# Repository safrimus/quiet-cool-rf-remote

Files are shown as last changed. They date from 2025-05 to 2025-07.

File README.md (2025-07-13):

# Quiet Cool RF Remote with ESPHOME
Operate your remote controlled QuietCool Fan from ESPHome or Arduino.

This project implements an RF remote control system for Quiet Cool fans using an ESP32 microcontroller and CC1101 RF module.
The system can control various fan speeds and modes through RF signals.

## WARNING WARNING WARNING
**This should have been obvious to me before.  Alas, it wasn't.  Each RF remote has a unique ID built-in, and this code literally
only works with my remote for that reason.  Currently, getting this working will take some effort decoding your individual remote. 
Lame, I know.  Whatcha gonna do?
**

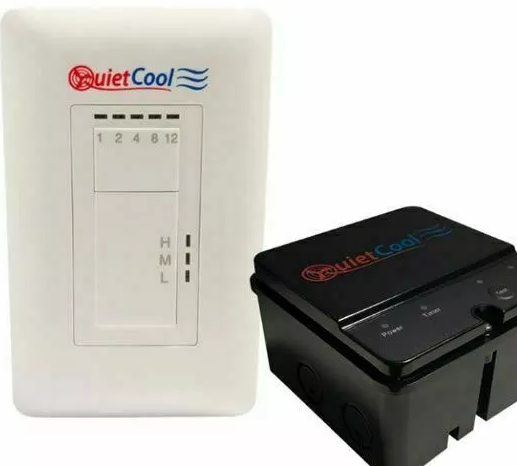
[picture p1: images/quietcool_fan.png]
QuietCool Remote


# TL;DR -- get it running on ESPHome
Get a generateic CC1101 board.  Like this [CC1101 Board](https://www.amazon.com/dp/B0D3W9GVRQ?ref=ppx_yo2ov_dt_b_fed_asin_title)

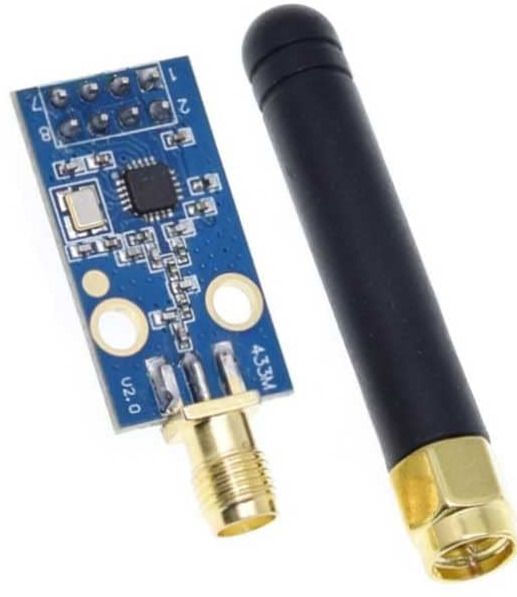
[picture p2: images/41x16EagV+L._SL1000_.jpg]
CC1101


Make these connections from your ESP32 to your CC1101 chip/board.

NOTE: the pinouts on these boards seem to be not reliable.  I had to trace them manually to figure out which header pin went to which CC1101 pin.  

| Module Pin | CC1101 Pin Name | CC1101 Pin #| ESP32 Pin |
|---|---|---|---|
| 1 | GND | 16,19,PAD | GND |
| 2 | VCC | - | 3.3V |
| 3 | GDO0 | 6 | GPIO13 |
| 4 | CSn | 7 | GPIO15 |
| 5 | SCK | 1 | GPIO18 |
| 6 | MOSI | 20 | GPIO23 |
| 7 | MISO | 2 | GPIO19 |
| 8 | GDO2 | 3 | GPIO12 |

## TL;DR -- get it running on ESPHome from ESPHome Builder on HomeAssistant

* Go to ESPHome Builder
* Click "+ NEW DEVICE" at the bottom of the screen
* Click `CONTINUE`
* name your fan
* click the ESP32 type you have.
* click `SKIP`
* on your new entry, click `EDIT`
* add the following to the bottom of the file:
```yaml
spi:
  clk_pin: 18
  mosi_pin: 23
  miso_pin: 19

external_components:
  - source:
      type: git
      url: https://github.com/ccrome/quiet-cool-rf-remote.git
      ref: main
    components: [ quiet_cool ]

fan:
  - platform: quiet_cool
    name: QuietCool fan
    cs_pin: 15
    gdo0_pin: 13
    gdo2_pin: 12
    remote_id: [0x2D, 0xD4, 0x06, 0xCB, 0x00, 0xF7, 0xF2]
# optional variables
#    center_freq_mhz: 433.897
#    deviation_khz: 10
```
* click `INSTALL` and install it in the normal ESPHome ways...

## TL;DR -- get it running on ESPHome, building locally

Create a `secrets.yaml` file
```yaml
wifi_ssid: <ssid>
wifi_password: <wifi password>
api_enctryption_key: <api key>
ota_password: <ota password>
```

compile, upload, and run
```
esphome compile quietcool-fan-example.yaml && \
esphome upload --device /dev/ttyUSB0 quietcool-fan-example.yaml  && \
esphome logs --device /dev/ttyUSB0 quietcool-fan-example.yaml
```

If everything is working, you should see
```
[16:48:24][D][quietcool:168]: gdo0_pin = 13, gdo2_pin = 12
[16:48:24][I][quietcool:174]: Starting CC1101 setup
[16:48:24][D][quietcool:041]: sck:18, miso:19, mosi:23, csn:15
[16:48:24][I][quietcool:047]: CC1101 VERSION READ: 0x00
[16:48:24][I][quietcool:047]: CC1101 VERSION READ: 0x14
[16:48:24][I][quietcool:049]: CC1101 detected!
[16:48:24][I][quietcool:179]: CC1101 ready
[16:48:24][D][empty_fan.fan:022]: QuietCool initialized
```

# Configuration

## Required Configuration

The `remote_id` field is **required** and must match your specific QuietCool remote. This is a 7-byte identifier that uniquely identifies your remote control.

> **Note:** QuietCool fans can pair with multiple remotes. This means you may not need to decode your existing remote's ID. Instead, you can simply pair this new ESPHome-based remote (with its own `remote_id`) to your fan, and both your original remote and the Home Assistant remote should work together.  This has yet to be tested.

### Finding Your Remote ID

NOTE:  you may not need to decode your existing remote's ID.  Instead, you can simply pair this new ESPHome-based remote (with its own `remote_id`) to your fan, and both your original remote and the Home Assistant remote should work together.  This has yet to be tested.

To find your remote ID, you can:
1. Use an RTL-SDR to capture signals from your physical remote
2. Analyze the captured signals to extract the remote ID
3. Or use the default value as a starting point: `[0x2D, 0xD4, 0x06, 0xCB, 0x00, 0xF7, 0xF2]`

### Example Configuration

```yaml
fan:
  - platform: quiet_cool
    name: QuietCool fan
    cs_pin: 15
    gdo0_pin: 13
    gdo2_pin: 12
    remote_id: [0x2D, 0xD4, 0x06, 0xCB, 0x00, 0xF7, 0xF2]
    # Optional:
    # center_freq_mhz: 433.897
    # deviation_khz: 10
```

---

### QuietCool YAML Configuration Options

| Option | Required | Type | Default | Description |
|---|---|---|---|---|
| `name` | Yes | string | | The name of the fan in Home Assistant. |
| `platform` | Yes | string | | Must be `quiet_cool`. |
| `cs_pin` | Yes | int | | SPI chip select pin for CC1101. |
| `gdo0_pin` | Yes | int | | GDO0 pin from CC1101 (used for TX status). |
| `gdo2_pin` | Yes | int | | GDO2 pin from CC1101 (can be -1 if unused). |
| `remote_id` | Yes | list[hex] | | 7-byte unique ID for your remote (see above). |
| `center_freq_mhz` | No | float | 433.897 | Center frequency in MHz for RF transmission. |
| `deviation_khz` | No | float | 10 | Frequency deviation (spread) in kHz for FSK modulation. |

**Note:** You must also define the SPI bus pins in your YAML:

```yaml
spi:
  clk_pin: 18
  mosi_pin: 23
  miso_pin: 19
```

## Recent Improvements

### Transmission System Overhaul
- **Consolidated bit conversion logic**: Unified logging and transmission to ensure consistency
- **Improved reliability**: Fixed potential timing and synchronization issues
- **Better debugging**: Enhanced logging with bit-level visibility
- **Configurable remote ID**: Support for custom remote identifiers via YAML configuration

### Technical Changes
- Replaced string-based command system with byte arrays for better performance
- Consolidated `logBits` and `sendBitsFromBytes` functions to use shared logic
- Added configurable `remote_id` parameter throughout the stack
- Improved error handling and validation

# Run it on arduino
The arduino code doesn't do much by itself.  But it gets you going:

```
cd arduino
platformio run --target upload
```

## Hardware Requirements

- ESP32 DOIT DevKit V1
- CC1101 RF Module
- Wiring connections as follows:
  ```
  CC1101 Pin -> ESP32 Pin
  GND       -> GND
  VCC       -> 3.3V
  GDO0      -> GPIO13
  CSn       -> GPIO15
  SCK       -> GPIO18
  MOSI      -> GPIO23
  MISO      -> GPIO19
  GDO2      -> GPIO12
  ```

## Case
Here's a case for the parts that I used.

The source is here [in OnShape](https://cad.onshape.com/documents/23ba2be84b2f4dcf9bfd73fc/v/3fa4bea9b4bb4353b99b35e1/e/0985333c7a3d43ad0383c966)

### Step File

* The whole design: [QuietCoolCase.step](3d/step/QuietCoolCase.step)
* Or just the Top: [QuietCoolCaseTop.step](3d/step/QuietCoolCaseTop.step)
* and just the Bottom: [QuietCoolCaseBottom.step](3d/step/QuietCoolCaseBottom.step)

## Software Requirements

- PlatformIO

## Features

- Controls Quiet Cool fan system via RF signals
- Supports multiple fan speeds and timer durations
  - Speed
    - L
    - M
    - H
  - Duration
    - 1
    - 2
    - 4
    - 8
    - 12
    - off
    - on
- **Configurable remote ID** for compatibility with different remotes

# Reverse Engineering
I used an RTL-SDR.COM SDR like this:
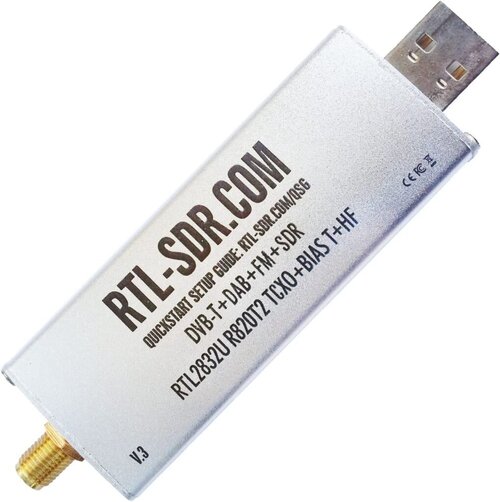
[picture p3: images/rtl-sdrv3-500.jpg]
RTL-SDR v3


And for software, I used Universal Radio Haacker.  Here's a recording of all the signals as they progress from H 1 2 4 8 12 ON OFF -> to medium -> low.  It was recorded with these settings

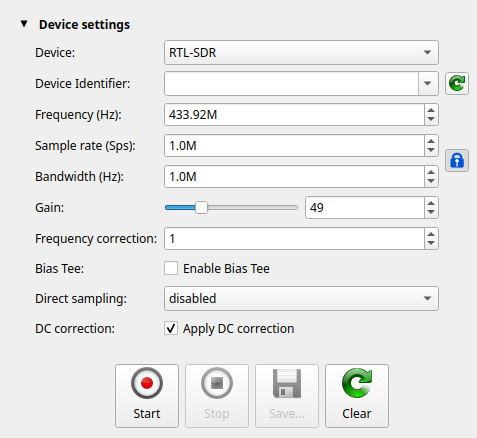
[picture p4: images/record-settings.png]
Settings


[Download the raw recording](recordings/RTL-SDR-20250510_080358-433_92MHz-1MSps-1MHz.complex16s.gz)

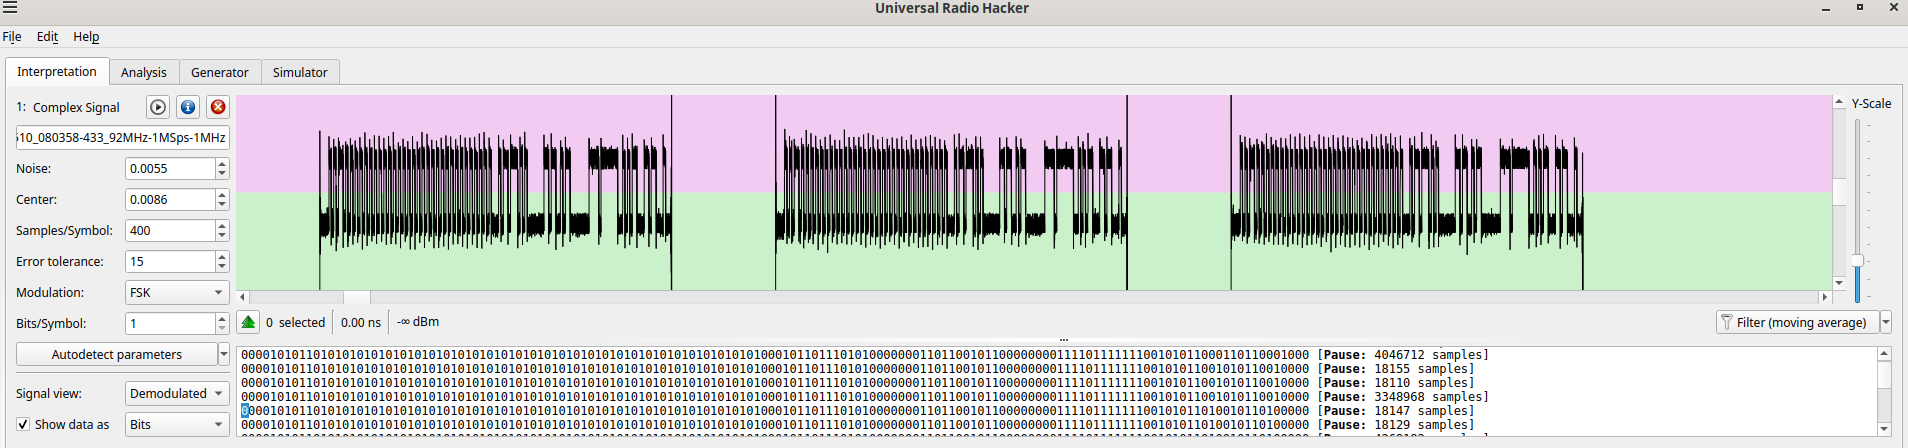
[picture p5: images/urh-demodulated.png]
Here's the signal demodulated


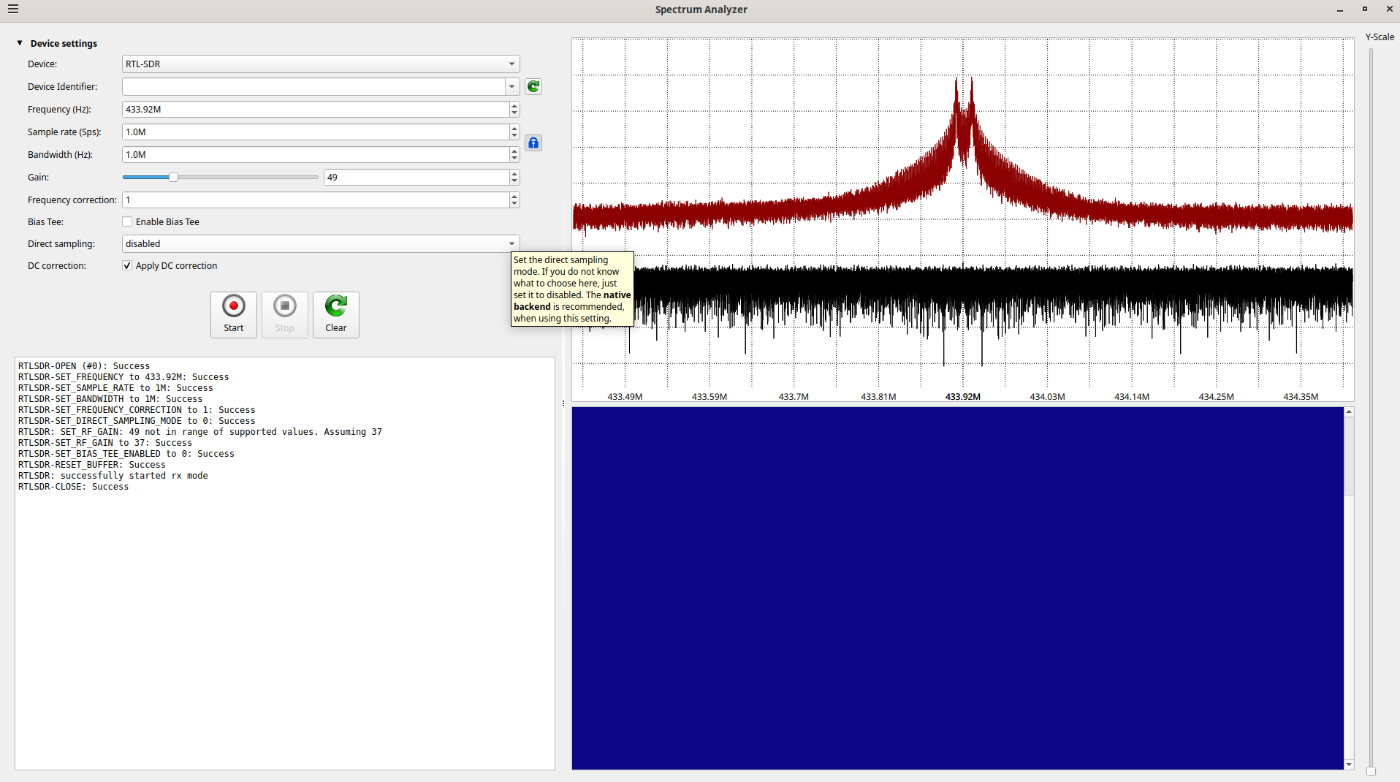
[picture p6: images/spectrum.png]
Spectrum Analysis


## Modulation
This remote uses FSK modulation at 433.92MHz.  The CC1101 RF module ended up transmitting high, so I reduced the frequency in the code to 433.897 to make it work.  If things don't work, check the actual frequency.

## Configuration

The system operates at 433.897 MHz and uses FSK modulation. The CC1101 module is configured for:
- Direct mode transmission
- No packet handling
- Raw data mode
- No CRC or preamble

## Building and Uploading

```pio run --target upload```

# TODO
* Implement the timers in the esphome UI

## License
MIT License

## Contributing

Contributions are welcome! Please feel free to submit a Pull Request.

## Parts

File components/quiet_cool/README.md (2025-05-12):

```yaml
# example configuration:

fan:
  - platform: quiet_cool
    name: QuietCool fan
    output: gpio_d1

output:
  - platform: gpio
    pin: D1
    id: gpio_d1
```

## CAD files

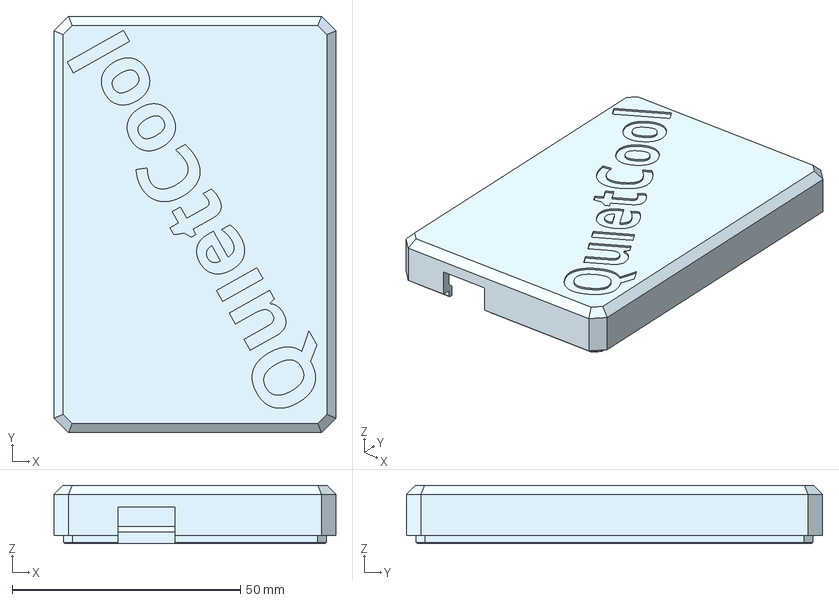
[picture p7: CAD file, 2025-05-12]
3d/step/QuietCoolCaseBottom.step
61.8 x 91.2 x 12.8 mm

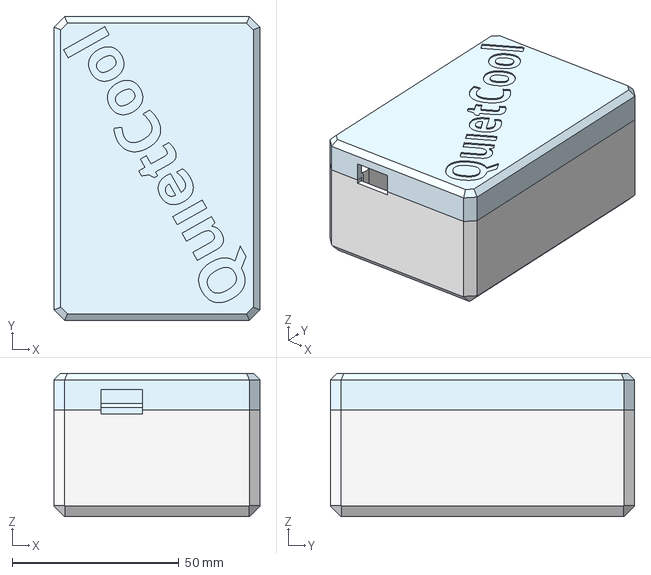
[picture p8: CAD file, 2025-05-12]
3d/step/QuietCoolCase.step
61.8 x 91.2 x 43.0 mm

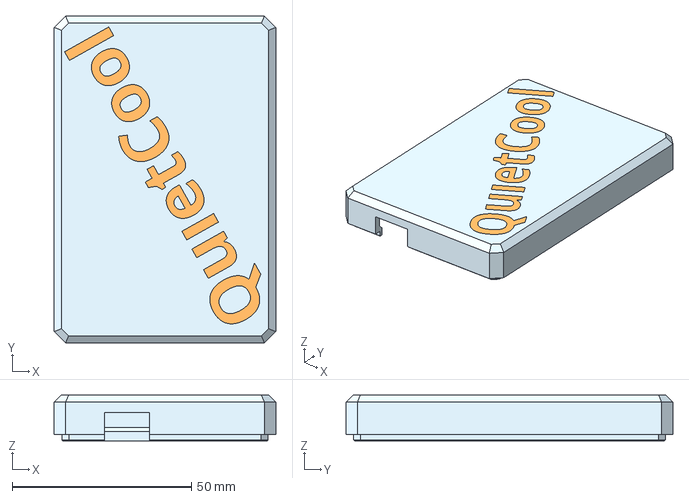
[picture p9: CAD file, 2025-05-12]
3d/step/QuietCoolCaseTop.step
61.8 x 91.2 x 12.8 mm

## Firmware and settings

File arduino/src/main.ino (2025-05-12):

#include <Arduino.h>
#include "quietcool.h"

/*
  hdr   cc1101
  1      19  GND
  2      18  VCC
  3      6   GDO0
  4      7   CSn
  5      1   SCK
  6      20  MOSI
  7      2   MISO
  8      3   GDO2
*/

// --- Pin configuration ---
#define CSN_PIN   15
#define GDO0_PIN  13
#define GDO2_PIN  12
#define SCK_PIN   18
#define MISO_PIN  19
#define MOSI_PIN  23
// #define FREQ_MHZ  433.92
#define FREQ_MHZ  433.897

// Create QuietCool instance with pin configuration
QuietCool qc(CSN_PIN, GDO0_PIN, GDO2_PIN, SCK_PIN, MISO_PIN, MOSI_PIN);

// --- Arduino setup ---
void setup() {
    Serial.begin(115200);
    delay(1000);
    qc.begin();
}

void loop() {
    // Example: Send a command to turn on high speed for 1 hour
    qc.send(QUIETCOOL_SPEED_HIGH, QUIETCOOL_DURATION_1H);
    delay(20000);  // Wait 5 seconds

    // Example: Turn off the fan
    qc.send(QUIETCOOL_SPEED_OFF, QUIETCOOL_DURATION_1H);
    delay(20000);  // Wait 5 seconds
}

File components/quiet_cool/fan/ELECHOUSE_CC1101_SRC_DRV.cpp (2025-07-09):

/*
  ELECHOUSE_CC1101.cpp - CC1101 module library
  Copyright (c) 2010 Michael.
    Author: Michael, <www.elechouse.com>
    Version: November 12, 2010

  This library is designed to use CC1101/CC1100 module on Arduino platform.
  CC1101/CC1100 module is an useful wireless module.Using the functions of the 
  library, you can easily send and receive data by the CC1101/CC1100 module. 
  Just have fun!
  For the details, please refer to the datasheet of CC1100/CC1101.
----------------------------------------------------------------------------------------------------------------
cc1101 Driver for RC Switch. Mod by Little Satan. With permission to modify and publish Wilson Shen (ELECHOUSE).
----------------------------------------------------------------------------------------------------------------
*/
#include <SPI.h>
#include "ELECHOUSE_CC1101_SRC_DRV.h"
#include <Arduino.h>

/****************************************************************/
#define   WRITE_BURST       0x40            //write burst
#define   READ_SINGLE       0x80            //read single
#define   READ_BURST        0xC0            //read burst
#define   BYTES_IN_RXFIFO   0x7F            //byte number in RXfifo
#define   max_modul 6

byte modulation = 2;
byte frend0;
byte chan = 0;
int pa = 12;
byte last_pa;
byte SCK_PIN;
byte MISO_PIN;
byte MOSI_PIN;
byte SS_PIN;
byte GDO0;
byte GDO2;
byte SCK_PIN_M[max_modul];
byte MISO_PIN_M[max_modul];
byte MOSI_PIN_M[max_modul];
byte SS_PIN_M[max_modul];
byte GDO0_M[max_modul];
byte GDO2_M[max_modul];
byte gdo_set=0;
bool spi = 0;
bool ccmode = 0;
float MHz = 433.92;
byte m4RxBw = 0;
byte m4DaRa;
byte m2DCOFF;
byte m2MODFM;
byte m2MANCH;
byte m2SYNCM;
byte m1FEC;
byte m1PRE;
byte m1CHSP;
byte pc1PQT;
byte pc1CRC_AF;
byte pc1APP_ST;
byte pc1ADRCHK;
byte pc0WDATA;
byte pc0PktForm;
byte pc0CRC_EN;
byte pc0LenConf;
byte trxstate = 0;
byte clb1[2]= {24,28};
byte clb2[2]= {31,38};
byte clb3[2]= {65,76};
byte clb4[2]= {77,79};

/****************************************************************/
uint8_t PA_TABLE[8]     {0x00,0xC0,0x00,0x00,0x00,0x00,0x00,0x00};
//                       -30  -20  -15  -10   0    5    7    10
uint8_t PA_TABLE_315[8] {0x12,0x0D,0x1C,0x34,0x51,0x85,0xCB,0xC2,};             //300 - 348
uint8_t PA_TABLE_433[8] {0x12,0x0E,0x1D,0x34,0x60,0x84,0xC8,0xC0,};             //387 - 464
//                        -30  -20  -15  -10  -6    0    5    7    10   12
uint8_t PA_TABLE_868[10] {0x03,0x17,0x1D,0x26,0x37,0x50,0x86,0xCD,0xC5,0xC0,};  //779 - 899.99
//                        -30  -20  -15  -10  -6    0    5    7    10   11
uint8_t PA_TABLE_915[10] {0x03,0x0E,0x1E,0x27,0x38,0x8E,0x84,0xCC,0xC3,0xC0,};  //900 - 928
/****************************************************************
*FUNCTION NAME:SpiStart
*FUNCTION     :spi communication start
*INPUT        :none
*OUTPUT       :none
****************************************************************/
void ELECHOUSE_CC1101::SpiStart(void)
{
  // initialize the SPI pins
  pinMode(SCK_PIN, OUTPUT);
  pinMode(MOSI_PIN, OUTPUT);
  pinMode(MISO_PIN, INPUT);
  pinMode(SS_PIN, OUTPUT);

  // enable SPI
  #ifdef ESP32
  SPI.begin(SCK_PIN, MISO_PIN, MOSI_PIN, SS_PIN);
  #else
  SPI.begin();
  #endif
}
/****************************************************************
*FUNCTION NAME:SpiEnd
*FUNCTION     :spi communication disable
*INPUT        :none
*OUTPUT       :none
****************************************************************/
void ELECHOUSE_CC1101::SpiEnd(void)
{
  // disable SPI
  SPI.endTransaction();
  SPI.end();
}
/****************************************************************
*FUNCTION NAME: GDO_Set()
*FUNCTION     : set GDO0,GDO2 pin for serial pinmode.
*INPUT        : none
*OUTPUT       : none
****************************************************************/
void ELECHOUSE_CC1101::GDO_Set (void)
{
    pinMode(GDO0, OUTPUT);
    pinMode(GDO2, INPUT);
}
/****************************************************************
*FUNCTION NAME: GDO_Set()
*FUNCTION     : set GDO0 for internal transmission mode.
*INPUT        : none
*OUTPUT       : none
****************************************************************/
void ELECHOUSE_CC1101::GDO0_Set (void)
{
  pinMode(GDO0, INPUT);
}
/****************************************************************
*FUNCTION NAME:Reset
*FUNCTION     :CC1101 reset //details refer datasheet of CC1101/CC1100//
*INPUT        :none
*OUTPUT       :none
****************************************************************/
void ELECHOUSE_CC1101::Reset (void)
{
    digitalWrite(SS_PIN, LOW);
    delay(1);
    digitalWrite(SS_PIN, HIGH);
    delay(1);
    digitalWrite(SS_PIN, LOW);
    while(digitalRead(MISO_PIN));
  SPI.transfer(CC1101_SRES);
  while(digitalRead(MISO_PIN));
    digitalWrite(SS_PIN, HIGH);
}
/****************************************************************
*FUNCTION NAME:Init
*FUNCTION     :CC1101 initialization
*INPUT        :none
*OUTPUT       :none
****************************************************************/
void ELECHOUSE_CC1101::Init(void)
{
  setSpi();
  SpiStart();                   //spi initialization
  digitalWrite(SS_PIN, HIGH);
  digitalWrite(SCK_PIN, HIGH);
  digitalWrite(MOSI_PIN, LOW);
  Reset();                    //CC1101 reset
  RegConfigSettings();            //CC1101 register config
  SpiEnd();
}
/****************************************************************
*FUNCTION NAME:SpiWriteReg
*FUNCTION     :CC1101 write data to register
*INPUT        :addr: register address; value: register value
*OUTPUT       :none
****************************************************************/
void ELECHOUSE_CC1101::SpiWriteReg(byte addr, byte value)
{
  SpiStart();
  digitalWrite(SS_PIN, LOW);
  while(digitalRead(MISO_PIN));
  SPI.transfer(addr);
  SPI.transfer(value); 
  digitalWrite(SS_PIN, HIGH);
  SpiEnd();
}
/****************************************************************
*FUNCTION NAME:SpiWriteBurstReg
*FUNCTION     :CC1101 write burst data to register
*INPUT        :addr: register address; buffer:register value array; num:number to write
*OUTPUT       :none
****************************************************************/
void ELECHOUSE_CC1101::SpiWriteBurstReg(byte addr, byte *buffer, byte num)
{
  byte i, temp;
  SpiStart();
  temp = addr | WRITE_BURST;
  digitalWrite(SS_PIN, LOW);
  while(digitalRead(MISO_PIN));
  SPI.transfer(temp);
  for (i = 0; i < num; i++)
  {
  SPI.transfer(buffer[i]);
  }
  digitalWrite(SS_PIN, HIGH);
  SpiEnd();
}
/****************************************************************
*FUNCTION NAME:SpiStrobe
*FUNCTION     :CC1101 Strobe
*INPUT        :strobe: command; //refer define in CC1101.h//
*OUTPUT       :none
****************************************************************/
void ELECHOUSE_CC1101::SpiStrobe(byte strobe)
{
  SpiStart();
  digitalWrite(SS_PIN, LOW);
  while(digitalRead(MISO_PIN));
  SPI.transfer(strobe);
  digitalWrite(SS_PIN, HIGH);
  SpiEnd();
}
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

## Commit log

2025-07-08 broke down the commands into symantic pieces
    [quietcool.cpp]
2025-07-08 Add configurable remote_id support
    - Add remote_id as required YAML configuration option
    - Replace static REMOTE_ID array with instance-specific remote_id
    - Update QuietCool constructor to accept remote_id parameter
    - Add set_remote_id method to QuietCoolFan class
    - Propagate remote_id from YAML through Python to C++ layer
    - Maintain backward compatibility with default remote_id values
    This allows users to specify their own remote ID in the YAML configuration
    to match their specific QuietCool remote, making the component more flexible
    and user-friendly.
    [quietcool.cpp]
2025-07-09 fix fan off state
    [quietcool.cpp]
2025-07-10 fixed up the debug printing
    [quietcool.cpp]
